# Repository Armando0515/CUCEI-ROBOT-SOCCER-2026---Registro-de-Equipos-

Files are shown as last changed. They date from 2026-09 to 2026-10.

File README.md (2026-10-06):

# CUCEI-ROBOT-SOCCER-2026 

Una implementación de firmware robusta escrita para ESP32 para controlar un robot de fútbol con tracción diferencial utilizando mandos Bluetooth modernos (Xbox One/Series, PS4 DualShock, PS5 DualSense, Switch Pro Controller, etc.).

* INSTALACIÓN Y CONFIGURACIÓN DEL SOFTWARE:

 - Paso 1. Agregar la URL del Gestor de Tarjetas:
Abre Arduino IDE.
Ve a Archivo → Preferencias (o presiona Ctrl + ,).
Busca el campo Gestor de URLs Adicionales de Tarjetas.
Pega la siguiente URL: https://raw.githubusercontent.com/ricardoquesada/esp32-arduino-lib-builder/master/bluepad32_files/package_esp32_bluepad32_index.json
Da click en aceptar.

 - Paso 2: Instalar el Paquete de Placas
Dirígete a Herramientas → Placa → Gestor de tarjetas...
En el buscador escribe: ESP32 + Bluepad32
Selecciona el paquete e haz clic en Instalar.

 - Paso 3: Seleccionar la Placa Correcta
Ve a Herramientas → Placa → ESP32 + Bluepad32 Arduino.
Selecciona ESP32 Dev Module.
⚠️ Importante: NO selecciones el ESP32 Dev Module estándar de Espressif. Debes seleccionar la opción dentro del menú de ESP32 + Bluepad32 Arduino, de lo contrario el firmware no compilará o el Bluetooth no inicializará.

    * Enparejamiento del Control:
Carga el código: Graba el programa carro.ino en tu tarjeta ESP32.
Abre el monitor serie: Configura la velocidad en 115200 baudios.
Pon el mando en modo Emparejamiento:
Xbox (Modelo 1708+): Enciende el mando y mantén presionado el botón de vinculación superior hasta que el botón Xbox parpadee rápidamente.
PS4 / PS5: Mantén presionados los botones Share/Create + Botón PS simultáneamente hasta que la barra de luz parpadee en ráfagas dobles.
Conexión Automática: El ESP32 borra las llaves previas al iniciar (BP32.forgetBluetoothKeys()) y se conectará automáticamente al mando que esté buscando conexión.
El monitor serie mostrará "CONTROL XBOX CONECTADO" una vez establecida la vinculación o si quieres una conexión sencilla para cambiar de mando constamente deja dicha línea en el código.

CÓDIGO EN ROBOT: El código interpreta las palancas (joysticks) y las cuales podría traducir en movimiento físico en la cancha si así se quisiera. Las palancas analógicas de los mandos de Xbox o PS4 envían valores en el rango de -512 a 512 en cada eje.
Nosotros como prueba base recomendamos: 

- Joystick Izquierdo Eje Y (ly): Controla el avance y la reversa (se invierte el signo -ly porque mover la palanca hacia arriba entrega valores negativos).
- Joystick Izquierdo Eje X (lx): Controla la dirección y rotación (valores negativos a la izquierda, positivos a la derecha).

Pueden existir distintas formas de programarlo, por ejemplo un botón de aceleración y otro de reversa con valores constantes en ambos motores, esta parte queda a la imaginación y comodidades del equipo. 

 * COMPONENTES NECESARIOS PARA ARMADO FÍSICO:

Para cada equipo participante sera otorgado un chasis impreso en 3D obligatorio a usar como el siguiente: 

<p align="center">
  Esquema 2
</p>

En dicho chasis, se debera utilizar un par de motoreductores amarillos convencionales, los cuales estarán sujetos al chasis mediante tornillería y junto con su respectiva llanta usual. En cuestiones de alimentación se deberá contar con portapilas con capacidad de dos baterías de un tamaño y capacidad de 3.7V con su respectivo switch de encedido y apagado del robot, se recomienda dichas baterías por cuestiones de espacio en el chasis. Todo esto se puede interpretar mejor en la siguiente imagen. 

<p align="center">
  Esquema 1
</p>

A continuación se mostrará un circuito de conexión base, el uso de alimentación, microcontrolador y puente H es recomendado, estos apartados quedan a disposición de cada equipo, solo recuerden que debe tener conexión bluetooth y debe ser teleoperado. 

<p align="center">
  Esquema 3
</p>

- Videos de apoyo para competencia: 

1. Mando + esp32
https://youtu.be/V0a3dC67gJM

2. Teoría de control
https://youtu.be/EIrFNuoQGhM

3. Reglamento
https://youtu.be/po5NVeyT-dg

4. Circuito
https://youtu.be/W9Q4fKAUw64
 
Listo, ya con todas las bases anteriores puedes comenzar con el armado y programación de tu robot - soccer listo para competir. 
¡MUCHO ÉXITO A TODOS!

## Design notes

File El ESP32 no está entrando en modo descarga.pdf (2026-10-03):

El ESP32 no está entrando en modo descarga (bootloader). Prueba esto:

1. Mantén presionado BOOT (o IO0).
2. Inicia la carga desde Arduino IDE / esptool.
3. Cuando aparezca Connecting..., suelta BOOT.
4. Si no funciona, mantén BOOT, pulsa y suelta EN/RESET, y luego suelta BOOT.
5. Verifica que seleccionaste el puerto COM/serial correcto y que el cable USB permite datos.
6. Desconecta periféricos conectados a GPIO0, GPIO2, GPIO12 o GPIO15, ya que pueden alterar el modo de arranque.

El código Wrong boot mode detected (0x13) indica que el chip arrancó en modo normal en lugar del modo de descarga.

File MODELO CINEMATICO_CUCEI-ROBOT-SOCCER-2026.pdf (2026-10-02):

# CUCEI-ROBOT-SOCCER-2026

Dr. Erasmo Gabriel Martínez Soltero Dr. José de Jesús Hernández Barragán josed.hernandezb@academicos.udg.mx

1

# Modelo cinemático

Ecuaciones del modelo cinemático del robot móvil:

2

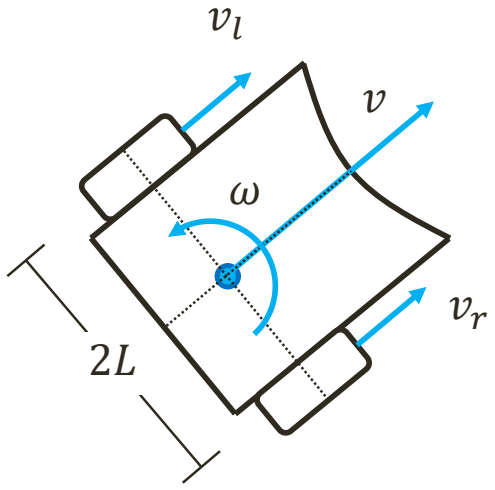
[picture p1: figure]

vl = v − Lω

vr = v + Lω

- vr velocidad lineal motor derecha.
- vl velocidad lineal motor izquierda.
- v velocidad lineal de avance.
- ω velocidad angular de rotación.
- 2L distancia entre ruedas.

# Modelo propuesto

Ecuaciones del modelo propuesto del robot móvil:

3

- Vr velocidad motor derecha.
- Vl velocidad motor izquierda.
- V velocidad de avance.
- Ω velocidad de rotación.
- C compensación de asimetría de los motores.

Vl = V − Ω + C

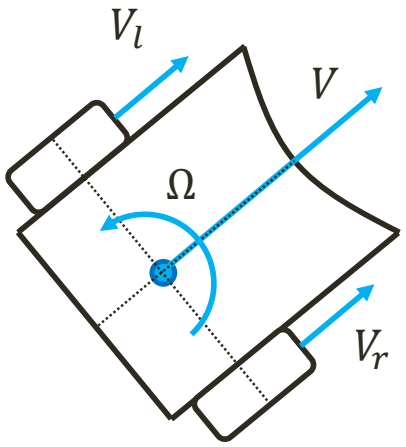
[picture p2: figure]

Ω | Vr = V + Ω − C

# Movimiento del robot

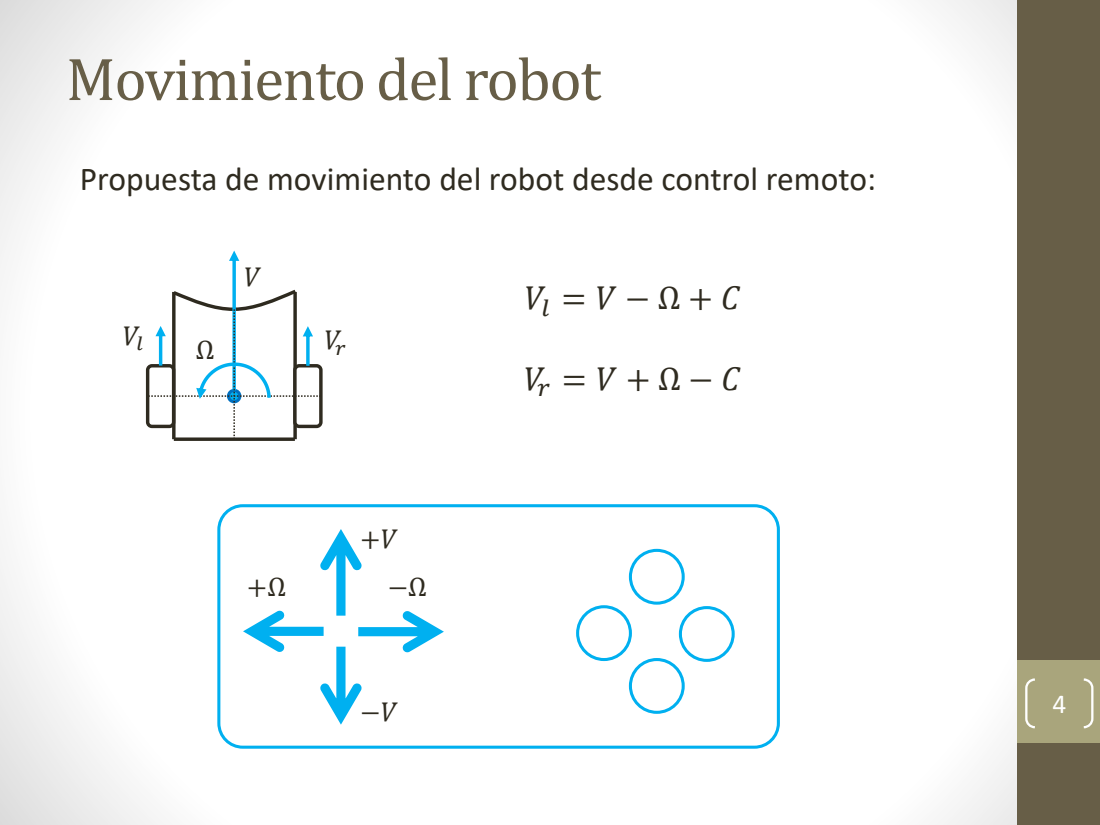
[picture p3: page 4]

Propuesta de movimiento del robot desde control remoto:

# Asimetría de los motores

Propuesta de compensación de asimetría de los motores:

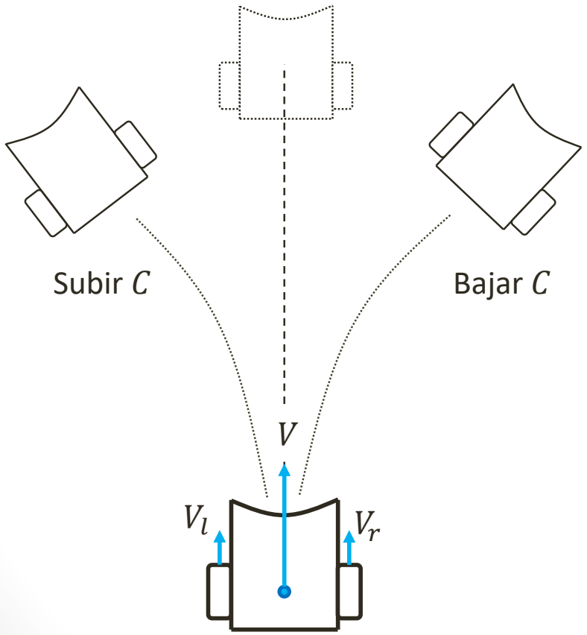
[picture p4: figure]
Subir C; Bajar C

5

Vl = V − Ω + C

Vr = V + Ω − C

# Saturación de los actuadores

Propuesta para evitar saturar los motores:

6

Vl = V − Ω + C

Vr = V + Ω − C

Velocidad máxima del motor:

−Vmax ≤ Vl ≤ Vmax
−Vmax ≤ Vr ≤ Vmax
Vm = max | Vl
, | Vr

Si Vm > Vmax hacer:

Vl ≔

Vmax
Vm

Vl

Vr ≔

Vmax
Vm

VR

# Recomendaciones finales

“Tomen lo aprendido y hagan algo más.”

7

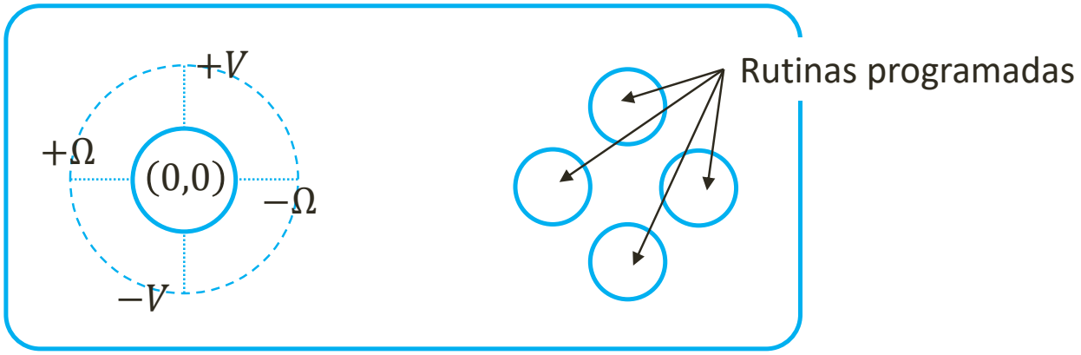
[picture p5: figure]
Rutinas programadas

“Cuidado con la zona muerta”

# Recomendaciones finales

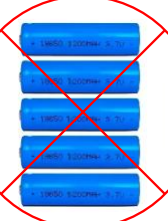
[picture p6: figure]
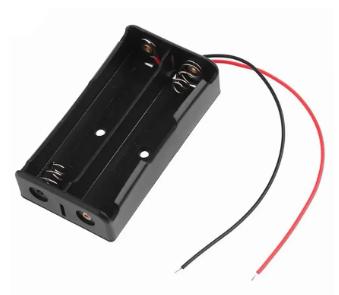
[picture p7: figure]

8

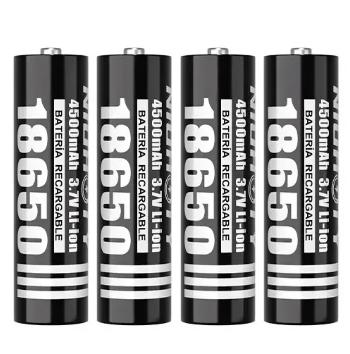
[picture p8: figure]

- 2x Pila 18650 + Porta pila.

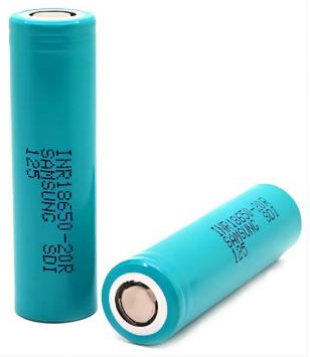
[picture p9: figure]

# Recomendaciones finales

9

- 2x Motores TT con llanta.

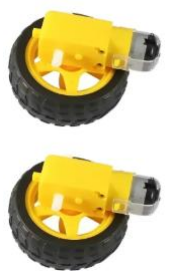
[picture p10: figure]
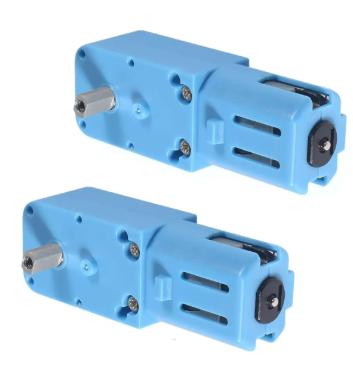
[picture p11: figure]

# Recomendaciones finales

10

- Esp32 + Regulador 5v.

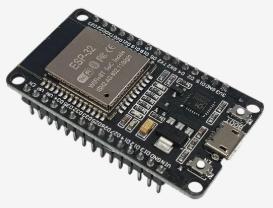
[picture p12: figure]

Esp32 con BT

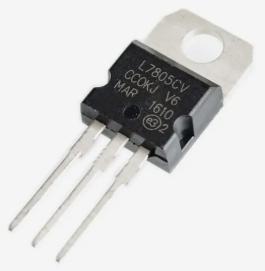
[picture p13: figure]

7805

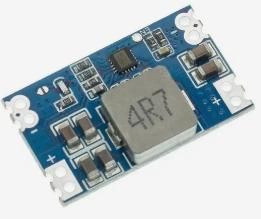
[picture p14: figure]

Step-Down

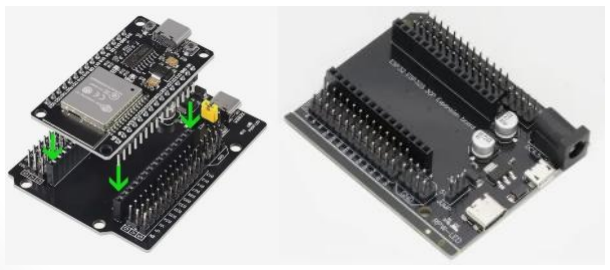
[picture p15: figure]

Shield

# Recomendaciones finales

11

- Puente H.

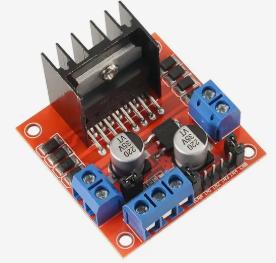
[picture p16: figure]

L298n

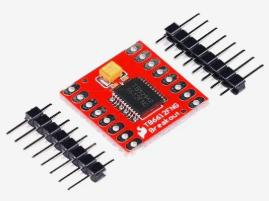
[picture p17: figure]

Tb6612fng

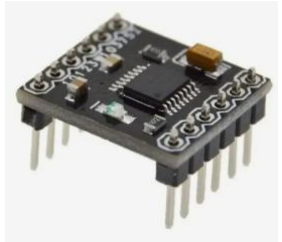
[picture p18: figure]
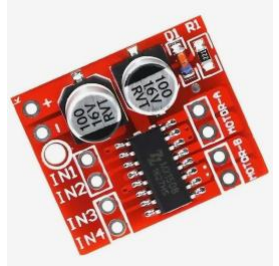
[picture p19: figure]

Mx1508 mini | Drv8833

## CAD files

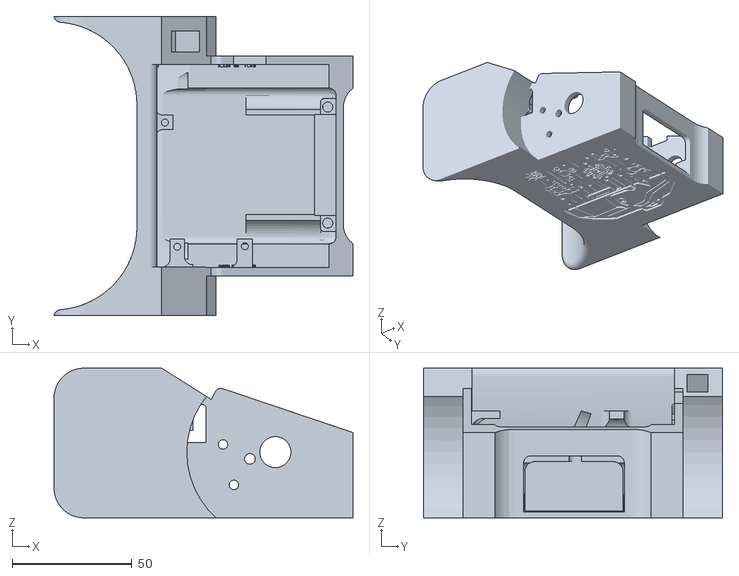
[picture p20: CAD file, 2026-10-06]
BASE DEL ROBOT MODIFICADO PARA ARDUINO UNO.stl
124.9 x 125.0 x 62.6

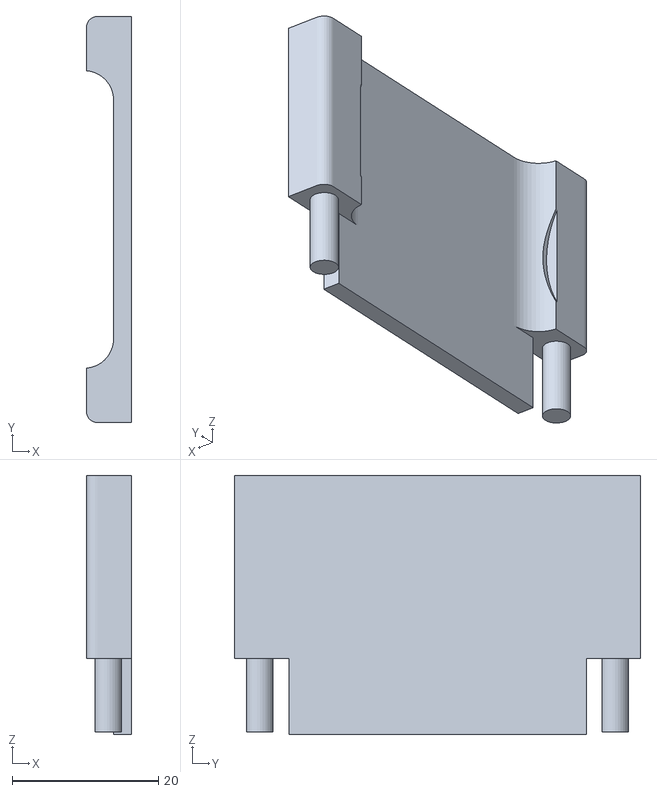
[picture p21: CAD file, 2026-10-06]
TAPA DE BATERIAS.stl
6.16 x 55.5 x 35.4

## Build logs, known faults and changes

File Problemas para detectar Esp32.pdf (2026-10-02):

Problemas para detectar Esp32
Al momento de conectar el esp32 en la computadora para programarlo no lo detecta Arduino Ide, pero el ESP32 no está quemado (muy caliente al tacto) podria ser debido a que necesitamos instalar los drivers necesarios (los archivos del sistema necesarios para que el sistema detecte correctamente el dispositivo)

Abriremos administrador de dispositivos.

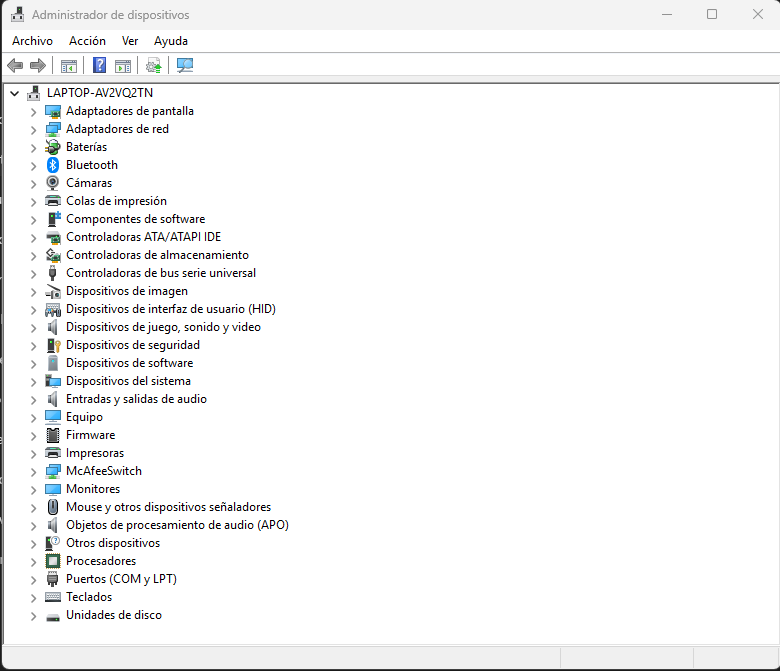
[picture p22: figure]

Una vez abierto conectaremos nuestro esp32 (o desconectaremos y volveremos a conectar) para así detectar si hay algún dispositivo nuevo en la lista, dado a que no nos lo detecta el Arduino IDE, lo más seguro es que lo detecte como dispositivo con una advertencia amarilla.

Al momento de conectarlo, abrirá automáticamente el apartado en el que se encuentra el dispositivo nuevo, por lo que únicamente necesitamos buscar un dispositivo con la advertencia amarilla.

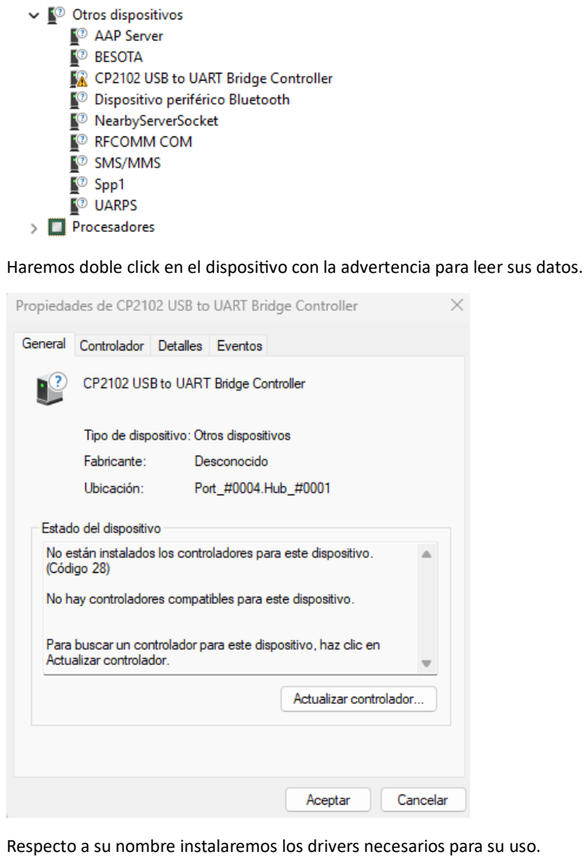
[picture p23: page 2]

Haremos doble click en el dispositivo con la advertencia para leer sus datos.

Respecto a su nombre instalaremos los drivers necesarios para su uso.

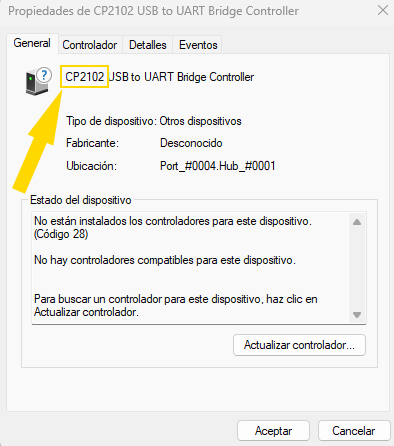
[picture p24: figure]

- Silicon Labs CP210x (CP2102 / CP2104 / CP2102N) (El driver necesario para el ejemplo)
- https://www.silabs.com/software-and-tools/usb-to-uart-bridge-vcp-drivers?tab=downloads (https://www.silabs.com/software-and-tools/usb-to-uart-bridge-vcp-drivers?tab=downloads)
- WCH CH340 / CH341 (CH340G / CH340C)
- Windows: https://www.wch-ic.com/downloads/CH341SER_EXE.html
- macOS/Linux: https://www.wch-ic.com/downloads/category/30.html
- WCH CH9102 / CH343 (CH9102X / CH9102F)
- https://www.wch-ic.com/downloads/CH343SER_EXE.html
- FTDI (FT232R / FT2232H)
- https://ftdichip.com/drivers/vcp-drivers/

Una vez identificado y descargado el driver necesario identificaremos la carpeta en la que se descargó, y crearemos una carpeta donde descomprimiremos el contenido del .zip que se haya descargado.

Lo seleccionaremos, haremos click derecho y copiaremos como ruta de acceso.

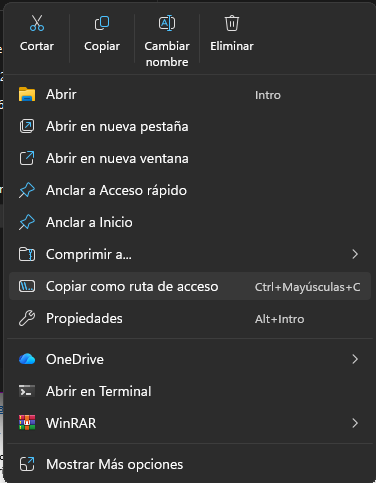
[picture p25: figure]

Entonces regresaremos al menú de nuestro dispositivo y daremos click en actualizar contolador.

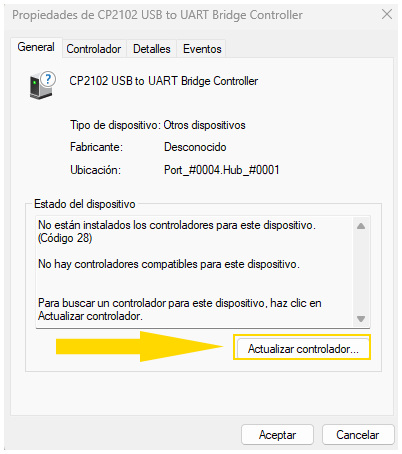
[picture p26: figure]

Entonces seleccionaremos “Buscar controladores en mi dispositivo”

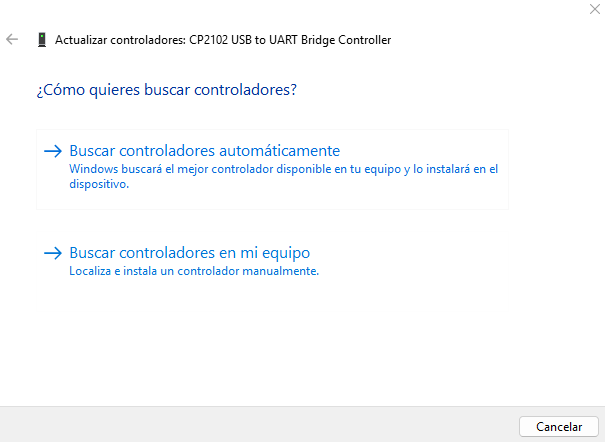
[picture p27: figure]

Entonces pegaremos la dirección que copiamos de la carpeta.

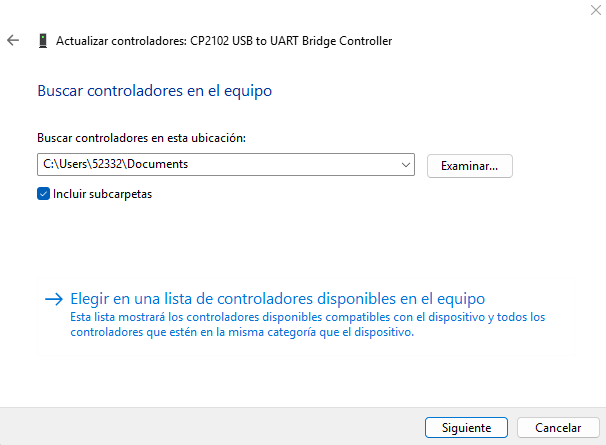
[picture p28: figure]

Y eliminaremos las comillas.

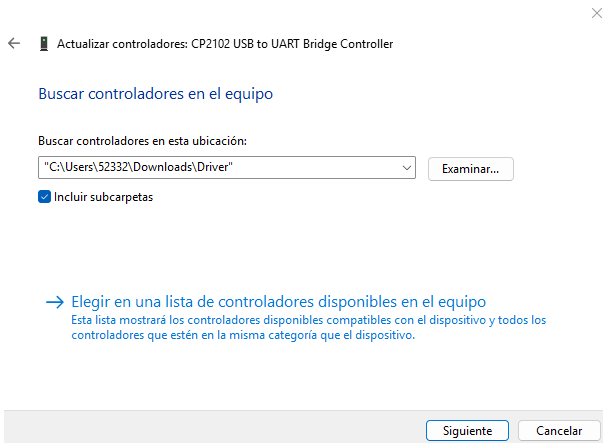
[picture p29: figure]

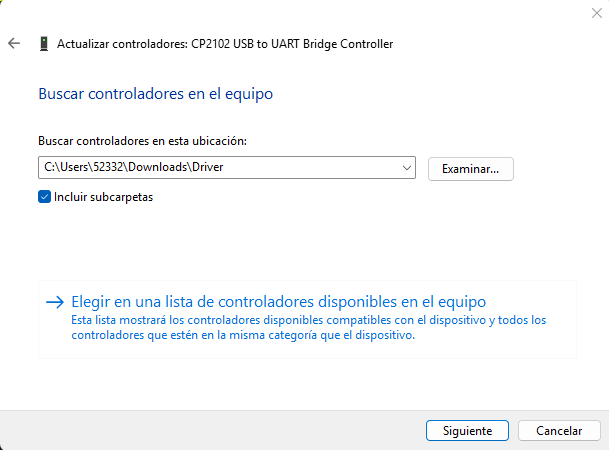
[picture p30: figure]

Entonces daremos click en Siguiente.

Procederá a instalarlo y mostrará lo siguiente.

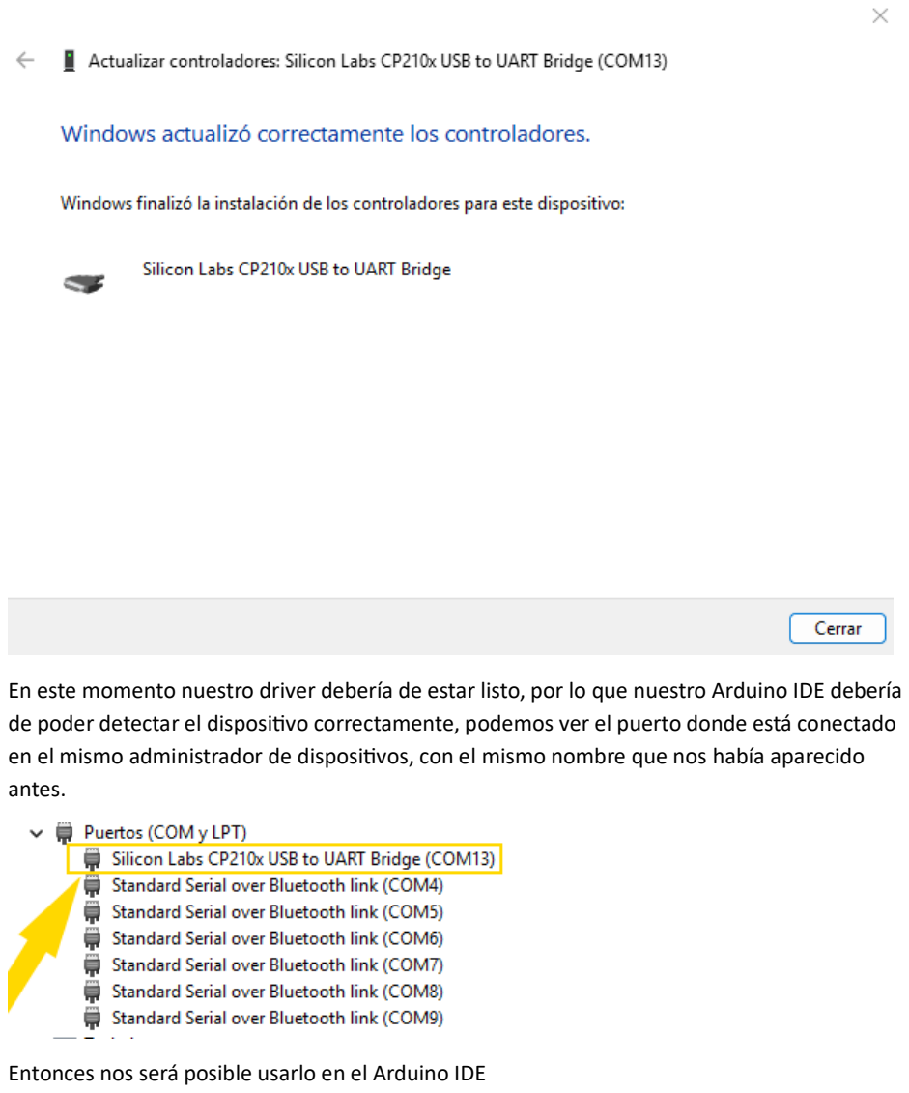
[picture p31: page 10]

En este momento nuestro driver debería de estar listo, por lo que nuestro Arduino IDE debería de poder detectar el dispositivo correctamente, podemos ver el puerto donde está conectado en el mismo administrador de dispositivos, con el mismo nombre que nos había aparecido antes.

Entonces nos será posible usarlo en el Arduino IDE

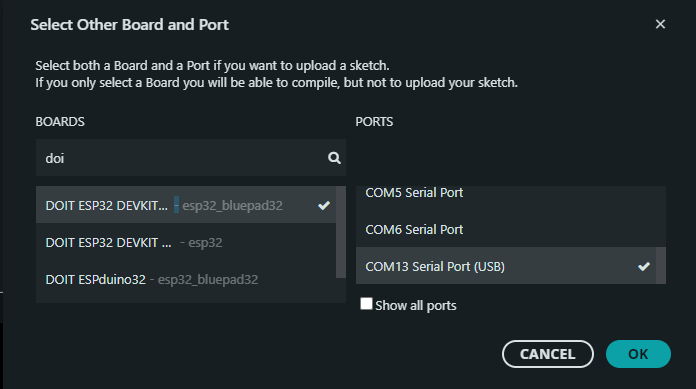
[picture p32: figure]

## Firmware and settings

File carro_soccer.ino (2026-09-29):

#include <Bluepad32.h>

GamepadPtr myGamepad = nullptr;

void onConnectedGamepad(GamepadPtr gp)
{
    myGamepad = gp;

    Serial.println();
    Serial.println("==============================");
    Serial.println("CONTROL PS4 CONECTADO");
    Serial.println("==============================");
}

void onDisconnectedGamepad(GamepadPtr gp)
{
    if (myGamepad == gp)
    {
        myGamepad = nullptr;
    }

    Serial.println();
    Serial.println("CONTROL DESCONECTADO");
}

void setup()
{
    Serial.begin(115200);
    delay(1000);

    Serial.println();
    Serial.println("ESP32 + Bluepad32");
    Serial.println("Esperando control PS4...");

    BP32.setup(&onConnectedGamepad, &onDisconnectedGamepad);

    // Solo para esta primera prueba
    BP32.forgetBluetoothKeys();
}

void loop()
{
    BP32.update();

    if (myGamepad && myGamepad->isConnected())
    {
        int16_t lx = myGamepad->axisX();
        int16_t ly = myGamepad->axisY();

        int16_t rx = myGamepad->axisRX();
        int16_t ry = myGamepad->axisRY();

        int16_t l2 = myGamepad->brake();
        int16_t r2 = myGamepad->throttle();

        bool A  = myGamepad->a();
        bool B  = myGamepad->b();
        bool X  = myGamepad->x();
        bool Y  = myGamepad->y();

        bool L1 = myGamepad->l1();
        bool R1 = myGamepad->r1();

        Serial.print("LX:");
        Serial.print(lx);

        Serial.print("\tLY:");
        Serial.print(ly);

        Serial.print("\tRX:");
        Serial.print(rx);

        Serial.print("\tRY:");
        Serial.print(ry);

        Serial.print("\tL2:");
        Serial.print(l2);

        Serial.print("\tR2:");
        Serial.print(r2);

        Serial.print("\tA:");
        Serial.print(A);

        Serial.print("\tB:");
        Serial.print(B);

        Serial.print("\tX:");
        Serial.print(X);

        Serial.print("\tY:");
        Serial.print(Y);

        Serial.print("\tL1:");
        Serial.print(L1);

        Serial.print("\tR1:");
        Serial.println(R1);
    }

    delay(20);
}
